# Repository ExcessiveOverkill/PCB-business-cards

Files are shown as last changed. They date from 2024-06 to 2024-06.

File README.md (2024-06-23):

# Persistence of vision display business cards

PCB cards designed for opensauce 2024 to give out to people

## Who is this repo for?
Anyone looking to make these cards for themselves or their own business.
It is NOT for people looking to make and sell the cards to others. (non-commercial use only)

## Software
- STM32CubeIDE
- python (numpy, cv2)
- Visual Studio Code

## Assembly
### The boards themselves
I ordered my PCBs from PCB way with .8mm thickness and ENIG coating since it is important to have a good contact surface for the batteries (and it looks nicer than HASL)

### Components
> [!WARNING]
> These exact parts I ordered in bulk from LCSC.
> The parts below are the closest matches I could find from DigiKey, but have not been tested yet

A DigiKey cart containing all of the needed components can be found [here](https://www.digikey.com/en/mylists/list/D8ND2J1IRM)
> [!IMPORTANT]
> The battery clips I used were from LCSC not DigiKey. The ones in the digikey cart have a slightly different footprint and may not fit perfectly.
> The exact clips I used can be found [here](https://www.lcsc.com/product-detail/Button-And-Strip-Battery-Connector_MYOUNG-MY-2032-30_C7525432.html)

Two standard CR2032 batteries are required, I used the cheap amazon ones.

### Placement
An interactive BOM can be found [here](opensauce2024/bom/ibom.html) (open in browser)

### Soldering
These boards are NOT designed to be hand-solderable.

I highly recommend at least a hotplate.

A stencil could be purchaced from a PCB manufacturer to make placing the solder paste easier, but it is not requred. (PCB and stencil files are in the repo)

The accelerometer is very susceptible to bad solder joints and will result in the card not activating when shaken. I had to resolder many of them to fix this.

## Programming
### Generating the graphics
Run "imageConverter.py", select which images or animations you want to display normally.

A second file select window will open for SECRET images to display. They will be displayed randomly according to the parameters set at the top of the python file.

Simply don't select anything if you do not want a secret image.

Images should be 32 pixel high PNGs, width does not matter, the card will show the entire image.

Once the images are selected, the program will show a demo of what will be displayed then write to a file defining the frame data.

### Programming the card
After the graphics have been saved, you simply build and upload the STM32 project using STM32CubeIDE.

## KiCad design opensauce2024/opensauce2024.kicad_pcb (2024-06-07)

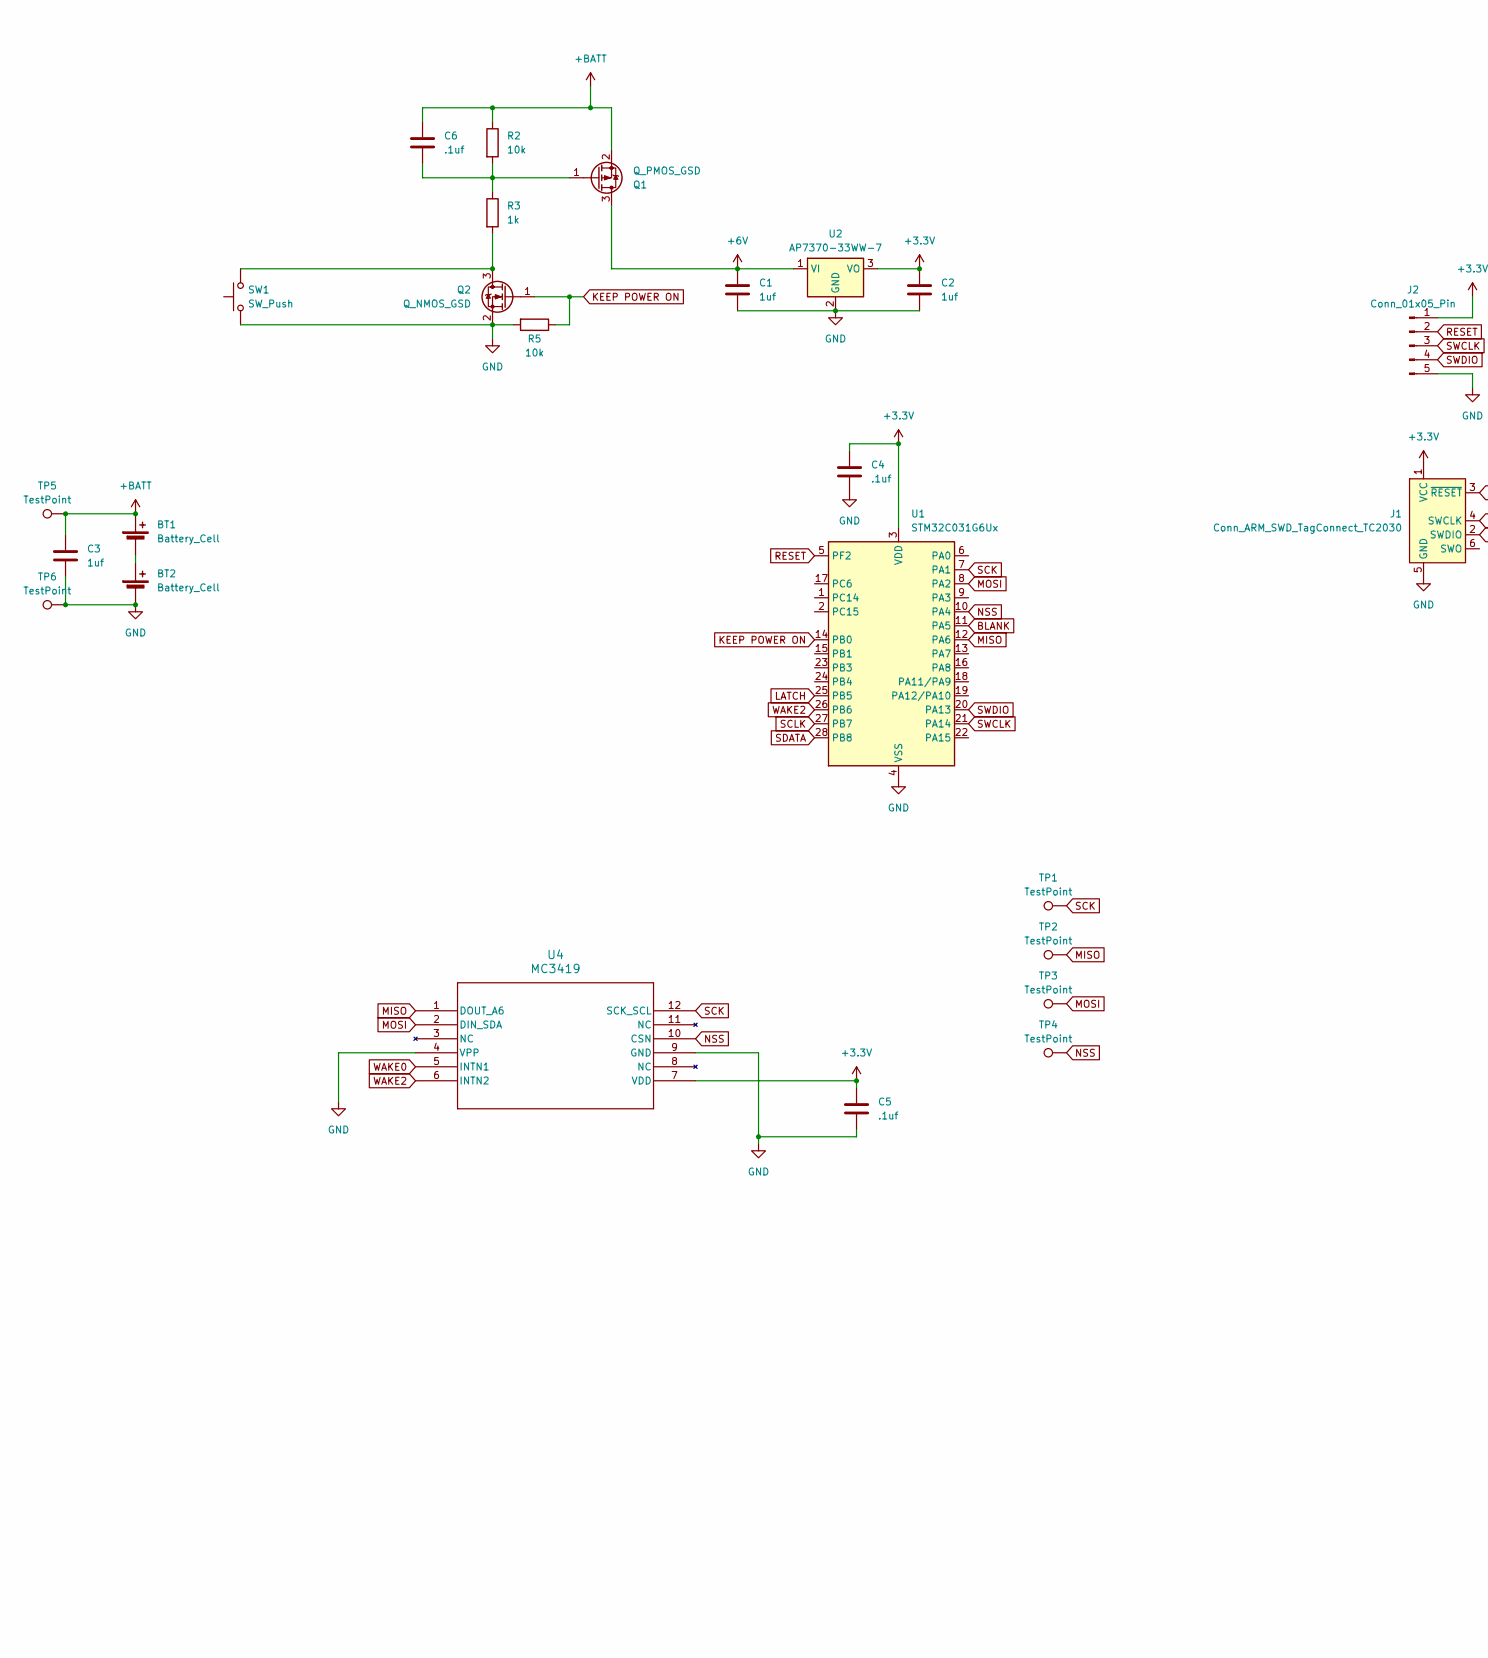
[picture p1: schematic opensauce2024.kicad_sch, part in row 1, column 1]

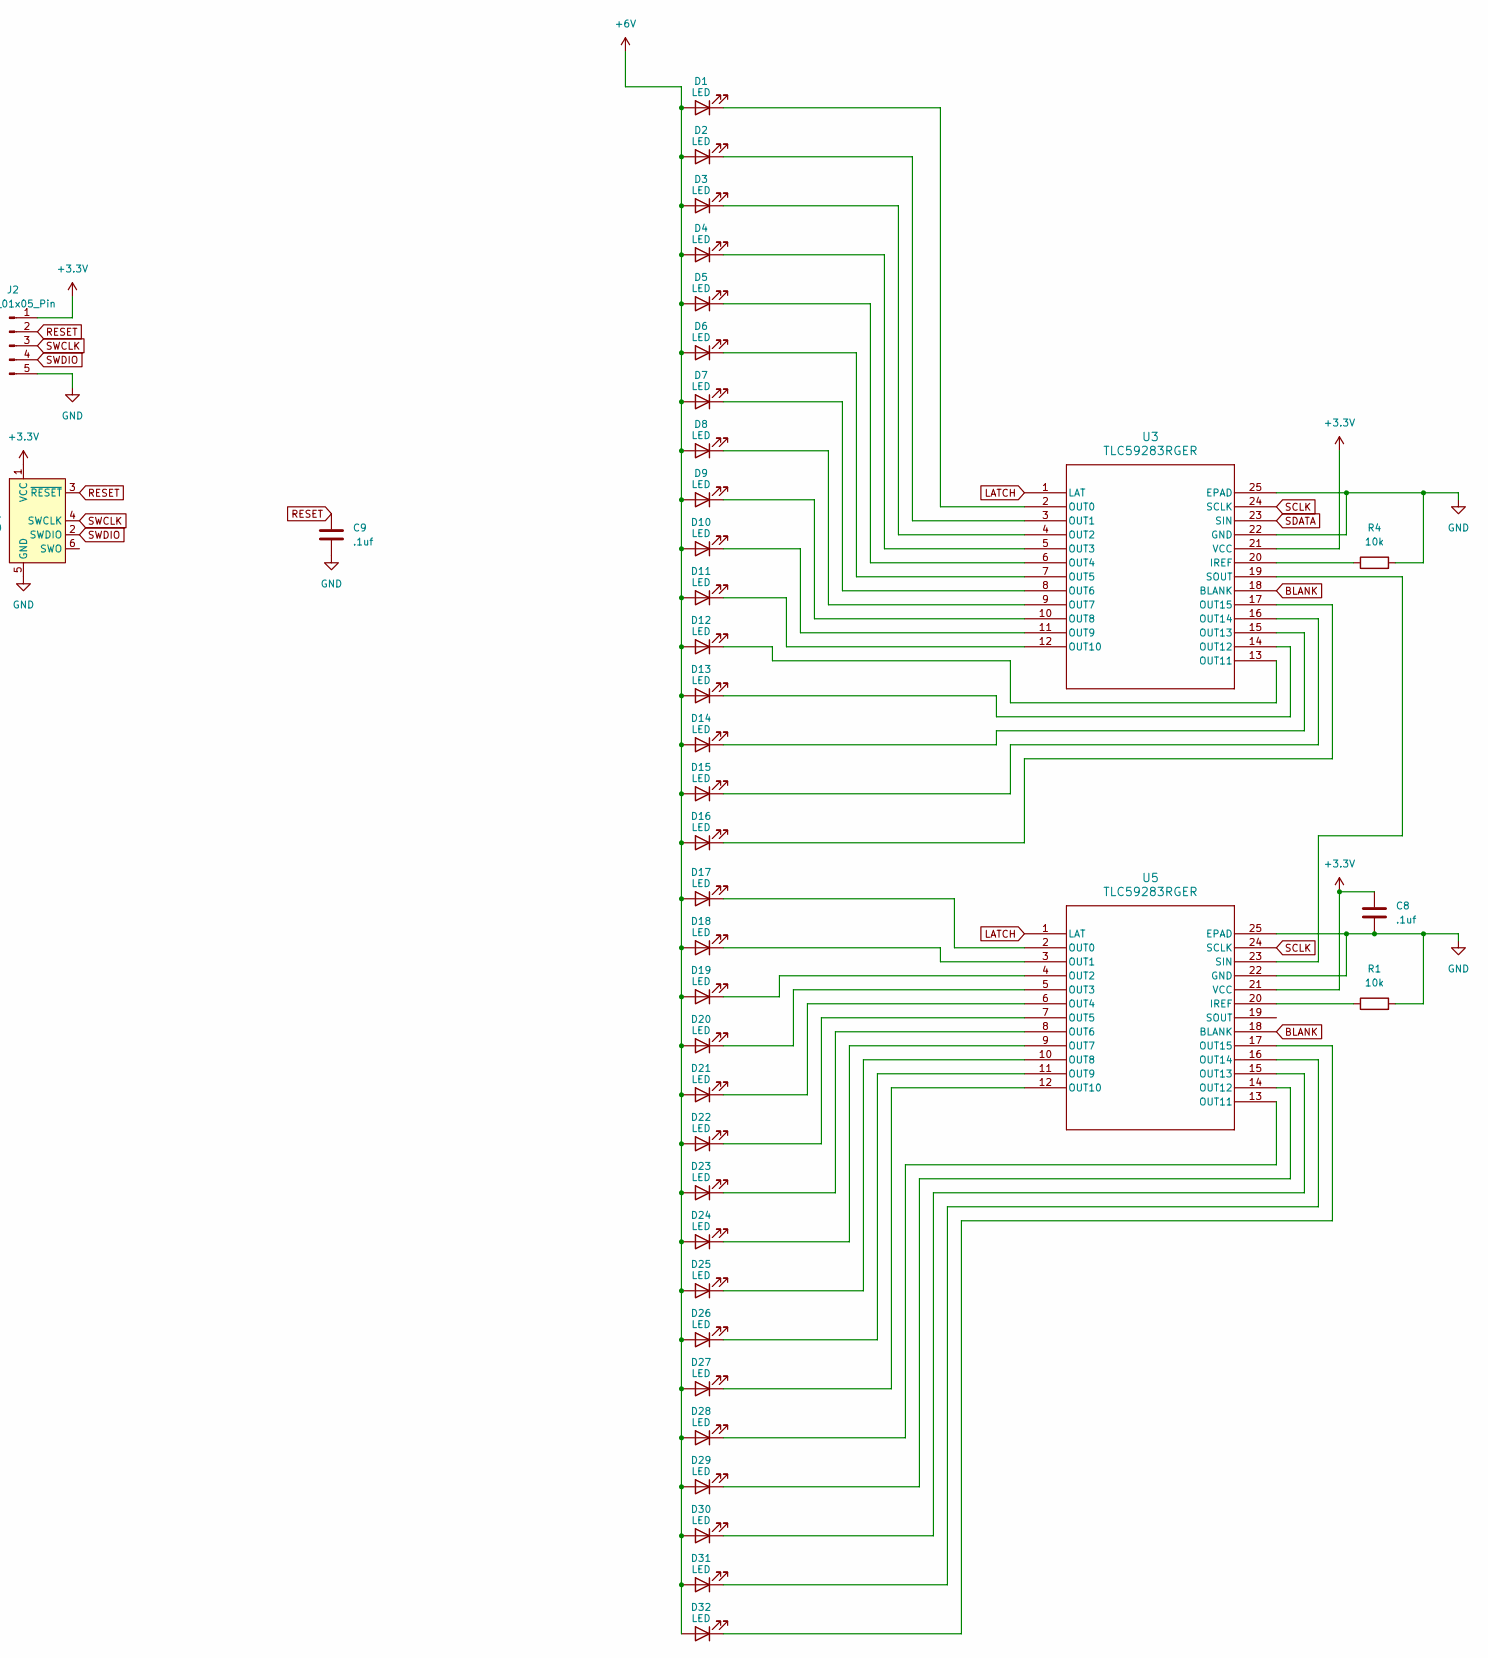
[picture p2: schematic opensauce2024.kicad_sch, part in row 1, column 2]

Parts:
BT1, BT2: Battery_Cell; cr2032
C1, C2, C3: 1uf; C_0603_1608Metric
C4, C5, C6, C8, C9: .1uf; C_0603_1608Metric
D1, D2, D3, D4, D5, D6, D7, D8, D9, D10, D11, D12, D13, D14, D15, D16, D17, D18, D19, D20, D21, D22, D23, D24, D25, D26, D27, D28, D29, D30, D31, D32: LED; LED_0603_1608Metric
J1: Conn_ARM_SWD_TagConnect_TC2030; Tag-Connect_TC2030-IDC-FP_2x03_P1.27mm_Vertical
J2: Conn_01x05_Pin; PinHeader_1x05_P2.54mm_Vertical
Q1: Q_PMOS_GSD; SOT-23
Q2: Q_NMOS_GSD; SOT-23
R1, R2, R4, R5: 10k; R_0603_1608Metric
R3: 1k; R_0603_1608Metric
SW1: SW_Push; SW_Push_1P1T_XKB_TS-1187A
TP1, TP2, TP3, TP4: TestPoint; TestPoint_Pad_D1.0mm
TP5, TP6: TestPoint; TestPoint_Pad_D2.0mm
U1: STM32C031G6Ux; QFN-28_4x4mm_P0.5mm
U2: AP7370-33WW-7; SOT25
U3, U5: TLC59283RGER; RGE24_2P1X2P1_TEX
U4: MC3419; LGA-12_2x2mm_P0.5mm

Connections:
+3.3V: C2.1, C4.1, C5.1, C8.1, J1.1 (VCC), J2.1, U1.3 (VDD), U2.3 (VO), U3.21 (VCC), U4.7 (VDD), U5.21 (VCC)
+6V: C1.1, D1.2 (A), D2.2 (A), D3.2 (A), D4.2 (A), D5.2 (A), D6.2 (A), D7.2 (A), D8.2 (A), D9.2 (A), D10.2 (A), D11.2 (A), D12.2 (A), D13.2 (A), D14.2 (A), D15.2 (A), D16.2 (A), D17.2 (A), D18.2 (A), D19.2 (A), D20.2 (A), D21.2 (A), D22.2 (A), D23.2 (A), D24.2 (A), D25.2 (A), D26.2 (A), D27.2 (A), D28.2 (A), D29.2 (A), D30.2 (A), D31.2 (A), D32.2 (A), Q1.3 (D), U2.1 (VI)
+BATT: BT1.1 (+), C3.1, C6.1, Q1.2 (S), R2.1, TP5.1
BLANK: U1.11 (PA5), U3.18 (BLANK), U5.18 (BLANK)
GND: BT2.2 (-), C1.2, C2.2, C3.2, C4.2, C5.2, C8.2, C9.2, J1.5 (GND), J2.5, Q2.2 (S), R1.2, R4.2, R5.2, SW1.1, TP6.1, U1.4 (VSS), U2.2 (GND), U3.22 (GND), U3.25 (EPAD), U4.4 (VPP), U4.9 (GND), U5.22 (GND), U5.25 (EPAD)
KEEP POWER ON: Q2.1 (G), R5.1, U1.14 (PB0)
LATCH: U1.25 (PB5), U3.1 (LAT), U5.1 (LAT)
MISO: TP2.1, U1.12 (PA6), U4.1 (DOUT_A6)
MOSI: TP3.1, U1.8 (PA2), U4.2 (DIN_SDA)
NSS: TP4.1, U1.10 (PA4), U4.10 (CSN)
unnamed: BT1.2 (-), BT2.1 (+)
unnamed: D1.1 (K), U3.2 (OUT0)
unnamed: D2.1 (K), U3.3 (OUT1)
unnamed: D3.1 (K), U3.4 (OUT2)
unnamed: D4.1 (K), U3.5 (OUT3)
unnamed: D5.1 (K), U3.6 (OUT4)
unnamed: D6.1 (K), U3.7 (OUT5)
unnamed: D7.1 (K), U3.8 (OUT6)
unnamed: D8.1 (K), U3.9 (OUT7)
unnamed: D9.1 (K), U3.10 (OUT8)
unnamed: D10.1 (K), U3.11 (OUT9)
unnamed: D11.1 (K), U3.12 (OUT10)
unnamed: D12.1 (K), U3.13 (OUT11)
unnamed: D13.1 (K), U3.14 (OUT12)
unnamed: D14.1 (K), U3.15 (OUT13)
unnamed: D15.1 (K), U3.16 (OUT14)
unnamed: D16.1 (K), U3.17 (OUT15)
unnamed: D17.1 (K), U5.2 (OUT0)
unnamed: D18.1 (K), U5.3 (OUT1)
unnamed: D19.1 (K), U5.4 (OUT2)
unnamed: D20.1 (K), U5.5 (OUT3)
unnamed: D21.1 (K), U5.6 (OUT4)
unnamed: D22.1 (K), U5.7 (OUT5)
unnamed: D23.1 (K), U5.8 (OUT6)
unnamed: D24.1 (K), U5.9 (OUT7)
unnamed: D25.1 (K), U5.10 (OUT8)
unnamed: D26.1 (K), U5.11 (OUT9)
unnamed: D27.1 (K), U5.12 (OUT10)
unnamed: D28.1 (K), U5.13 (OUT11)
unnamed: D29.1 (K), U5.14 (OUT12)
unnamed: D30.1 (K), U5.15 (OUT13)
unnamed: D31.1 (K), U5.16 (OUT14)
unnamed: D32.1 (K), U5.17 (OUT15)
unnamed: C6.2, Q1.1 (G), R2.2, R3.1
unnamed: Q2.3 (D), R3.2, SW1.2
unnamed: R4.1, U3.20 (IREF)
unnamed: U3.19 (SOUT), U5.23 (SIN)
unnamed: R1.1, U5.20 (IREF)
RESET: C9.1, J1.3 (~RESET), J2.2, U1.5 (PF2)
SCK: TP1.1, U1.7 (PA1), U4.12 (SCK_SCL)
SCLK: U1.27 (PB7), U3.24 (SCLK), U5.24 (SCLK)
SDATA: U1.28 (PB8), U3.23 (SIN)
SWCLK: J1.4 (SWCLK), J2.3, U1.21 (PA14)
SWDIO: J1.2 (SWDIO), J2.4, U1.20 (PA13)
WAKE0: U4.5 (INTN1)
WAKE2: U1.26 (PB6), U4.6 (INTN2)

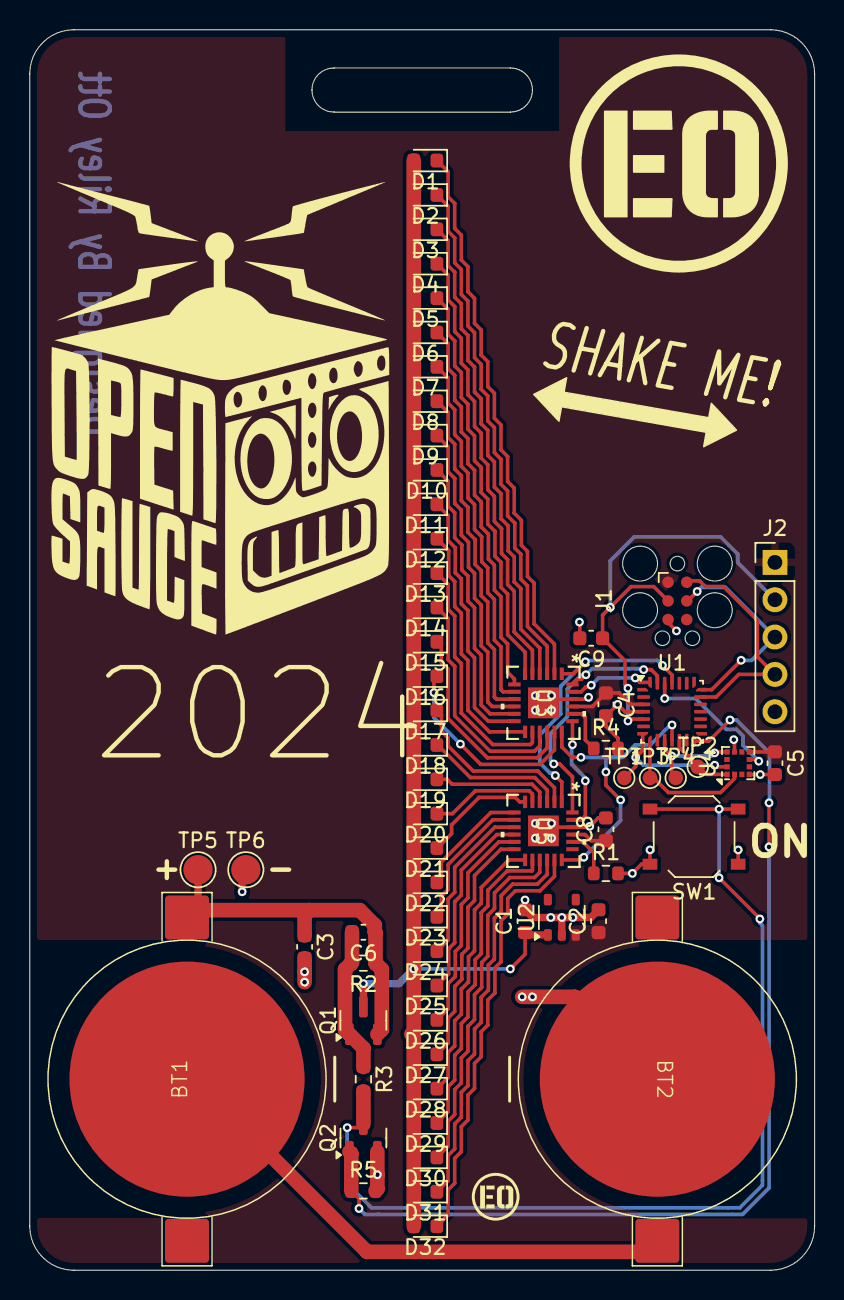
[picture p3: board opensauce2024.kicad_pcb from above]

Board: 2 copper layers, 53.4 x 84.4 mm, 63 parts (0 on the bottom side), 55 nets.

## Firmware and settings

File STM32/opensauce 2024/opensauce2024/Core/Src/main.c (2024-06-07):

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
/* Includes ------------------------------------------------------------------*/
#include "main.h"

/* USER CODE BEGIN Includes */
#include "ledDrivers.h"
#include "imageData.h"
#include "math.h"
/* USER CODE END Includes */

/* USER CODE BEGIN PD */
#define POWER_OFF_DELAY 30	// how many seconds of no movement before powering down
#define LED_ENABLE_ACCELERATION 6000

// use measured x accel values as "random" input
// max is 0x7FFE
// min is 1
// a point is counted each time the actual measured value falls between high and low range (inclusive), once enough points are accumulated, the random event is triggered
#define RANDOM_HIGH_RANGE 0x3FFF + RANDOM_CHANCE  	// mid-scale
#define RANDOM_LOW_RANGE 0x3FFF - RANDOM_CHANCE		// the wider this range, the more likely it will match
#define RANDOM_POINTS_REQUIRED RANDOM_POINTS
#define SECRET_IMAGE_DISPLAY_CYCLES SECRET_DISPLAY_CYCLES	// number of cycles to display the secret image once the random threshold is reached

//#define ANGLE_STABILIZATION_MODE 1	// enable stabilization mode, this displays animation frames based on the tilt angle of the card instead of playing the animation. frame display cycles should be set to 1 when using this

#define PI 3.14159265359


/* USER CODE END PD */


SPI_HandleTypeDef hspi1;

TIM_HandleTypeDef htim1;

/* USER CODE BEGIN PV */

// write addresses
const uint8_t ACCEL_MODE = 0x07;
const uint8_t ACCEL_SAMPLE_RATE = 0x08;
const uint8_t ACCEL_RANGE = 0x20;
const uint8_t ACCEL_INTERRUPT_ENABLE = 0x06;
const uint8_t ACCEL_GPIO_CONTROL = 0x33;
const uint8_t ACCEL_COMMUNICATION_CONTROL = 0x31;
const uint8_t ACCEL_INTERRUPT_STATUS = 0x14;

// read addresses
const uint8_t ACCEL_STATUS = 0x05 + 128;
const uint8_t ACCEL_READ_COUNT = 0x4b + 128;
const uint8_t ACCEL_X_DATA = 0x0d + 128;
const uint8_t ACCEL_RUN_STATUS = 0x13 + 128;

/* USER CODE END PV */

void SystemClock_Config(void);
static void MX_GPIO_Init(void);
static void MX_SPI1_Init(void);
static void MX_TIM1_Init(void);
/**
  * @brief  The application entry point.
  * @retval int
  */
int main(void)
{

  /* USER CODE BEGIN 1 */
	FLASH_OBProgramInitTypeDef OB;

	HAL_FLASHEx_OBGetConfig(&OB);
	if((OB.USERConfig & OB_BOR_ENABLE)){
	   HAL_FLASH_Unlock();
	   HAL_FLASH_OB_Unlock();

	   OB.OptionType = OPTIONBYTE_USER;
	   OB.USERType = OB_USER_BOR_EN;
	   OB.USERConfig = OB_BOR_DISABLE;

	   if ( HAL_FLASHEx_OBProgram(&OB) != HAL_OK )
		  {
			  HAL_FLASH_OB_Lock();
			  HAL_FLASH_Lock();
			  return HAL_ERROR;
		  }

		  HAL_FLASH_OB_Launch();

		  /* We should not make it past the Launch, so lock
		   * flash memory and return an error from function
		   */
		  HAL_FLASH_OB_Lock();
		  HAL_FLASH_Lock();
		  return HAL_ERROR;
	}

  /* USER CODE END 1 */

  /* MCU Configuration--------------------------------------------------------*/

  /* Reset of all peripherals, Initializes the Flash interface and the Systick. */
  HAL_Init();

  /* Configure the system clock */
  SystemClock_Config();

  /* Initialize all configured peripherals */
  MX_GPIO_Init();
  MX_SPI1_Init();
  MX_TIM1_Init();
  /* USER CODE BEGIN 2 */

  TIM1->CR1 |= 1;

  // lock on power
  HAL_GPIO_WritePin(KEEP_POWER_ON_GPIO_Port, KEEP_POWER_ON_Pin, GPIO_PIN_SET);
  //HAL_Delay(100);
  disableLEDs();
  setLEDs(0x80000001);
  enableLEDs();
  HAL_Delay(100);
  setLEDs(0);

  uint32_t tick_count = 0;
  uint32_t last_active_tick_count = 0;

  const uint32_t imageData[IMAGE_LENGTH] = IMAGE_DATA;
  const uint8_t normal_frame_cycles[IMAGE_LENGTH/FRAME_LENGTH] = FRAME_DISPLAY_CYCLES;

  #ifdef SECRET_IMAGE_DATA
  	  const uint32_t secretImageData[SECRET_IMAGE_LENGTH] = SECRET_IMAGE_DATA;
  	  const uint8_t secret_frame_cycles[SECRET_IMAGE_LENGTH/SECRET_FRAME_LENGTH] = SECRET_FRAME_DISPLAY_CYCLES;
  #endif


  char spi_buf[10];
  char spi_read_buf[10];

  #ifdef ANGLE_STABILIZATION_MODE
  	  int16_t y_accel_raw = 0;
  	  int32_t angle_step = 0;
  	  int32_t x_accel_zero_average = 0;
  	  int32_t y_accel_zero_average = 0;
  #endif

  int16_t x_accel_raw = 0;


  int32_t low_cut_integrator_rate = 10; // max accel magnitude to reduce toward zero each cycle. this is used to remove affects of gravity
  int32_t x_low_cut_integrator = 0;

  int32_t x_accel = 0;
  int32_t x_accel_interpolated = 0;
  int32_t x_accel_previous = 0;
  uint32_t accel_last_update_time = 0;	// us
  uint32_t accel_update_period = 1000; 	// us (1000Hz)
  int32_t max_dynamic_accel = 0x7FFF; // acceleration needed to reach ends of image, this should adjust based on the measured max acceleration


  int32_t x_accel_magnitude_average = 0;

  int32_t image_line = 0;

  int32_t max_cycle_accel = 0;
  int32_t min_cycle_accel = 0;
  uint32_t max_cycle_accel_time = 0;
  uint32_t min_cycle_accel_time = 0;

  uint32_t estimated_next_edge_time = 0;	// when we think we will be at the end of the shake motion again
  uint32_t frame_trigger_time = 0xFFFFFFFF;

  uint32_t random_points = 0;
  int32_t image_length = IMAGE_LENGTH;
  int32_t frame_length = FRAME_LENGTH;
  
  uint32_t current_frame_cycle = 0;
  uint32_t frame_display_cycles = normal_frame_cycles[0];

  uint32_t current_frame = 0;

  uint32_t secret_display_cycles = 0;

  uint32_t accel_read_attemps = 0;

  // send nothing to get SPI clk level set correctly
  HAL_SPI_Transmit(&hspi1, (uint8_t *)spi_buf, 1, 1);

  // configure accelerometer

  ACCEL_SELECT_GPIO_Port->ODR &= ~(1 << 4);
  spi_buf[0] = ACCEL_MODE;
  spi_buf[1] = 0b00000000;	// set to standby mode
  HAL_SPI_Transmit(&hspi1, (uint8_t *)spi_buf, 2, 1);
  ACCEL_SELECT_GPIO_Port->ODR |= (1 << 4);

  HAL_Delay(1);

  ACCEL_SELECT_GPIO_Port->ODR &= ~(1 << 4);
  spi_buf[0] = ACCEL_SAMPLE_RATE;
  spi_buf[1] = 0x0E;	// set sample rate (1000 Hz)
  HAL_SPI_Transmit(&hspi1, (uint8_t *)spi_buf, 2, 1);
  ACCEL_SELECT_GPIO_Port->ODR |= (1 << 4);

  ACCEL_SELECT_GPIO_Port->ODR &= ~(1 << 4);
  spi_buf[0] = ACCEL_INTERRUPT_ENABLE;
  spi_buf[1] = 0x80;	// enable sample (ACQ) interrupt
  HAL_SPI_Transmit(&hspi1, (uint8_t *)spi_buf, 2, 1);
  ACCEL_SELECT_GPIO_Port->ODR |= (1 << 4);

  ACCEL_SELECT_GPIO_Port->ODR &= ~(1 << 4);
  spi_buf[0] = ACCEL_GPIO_CONTROL;
  spi_buf[1] = 0xC0;	// set INTN2 pin as push/pull active high
  HAL_SPI_Transmit(&hspi1, (uint8_t *)spi_buf, 2, 1);
  ACCEL_SELECT_GPIO_Port->ODR |= (1 << 4);

  ACCEL_SELECT_GPIO_Port->ODR &= ~(1 << 4);
  spi_buf[0] = ACCEL_COMMUNICATION_CONTROL;
  spi_buf[1] = 0x10;	// swap INTN output pins
  HAL_SPI_Transmit(&hspi1, (uint8_t *)spi_buf, 2, 1);
  ACCEL_SELECT_GPIO_Port->ODR |= (1 << 4);

  ACCEL_SELECT_GPIO_Port->ODR &= ~(1 << 4);
  spi_buf[0] = ACCEL_RANGE;
  spi_buf[1] = 0b00100000;	// set +- 8G's
  HAL_SPI_Transmit(&hspi1, (uint8_t *)spi_buf, 2, 1);
  ACCEL_SELECT_GPIO_Port->ODR |= (1 << 4);

  ACCEL_SELECT_GPIO_Port->ODR &= ~(1 << 4);
  spi_buf[0] = ACCEL_MODE;
  spi_buf[1] = 0b00000001;	// set to wake mode
  HAL_SPI_Transmit(&hspi1, (uint8_t *)spi_buf, 2, 1);
  ACCEL_SELECT_GPIO_Port->ODR |= (1 << 4);


  tick_count = (tick_count & 0xFFFF0000) + TIM1->CNT;
  	if(TIM1->SR & 0b1){
  		tick_count += 0x10000;
  		TIM1->SR &= ~(1);
  	}

  accel_last_update_time = tick_count;


  /* USER CODE END 2 */

  /* Infinite loop */
  /* USER CODE BEGIN WHILE */
  while (1)
  {
	tick_count = (tick_count & 0xFFFF0000) + TIM1->CNT;
	if(TIM1->SR & 0b1){
		tick_count += 0x10000;
		TIM1->SR &= ~(1);
	}

	accel_read_attemps = 5;
	while(ACCEL_INTERRUPT_GPIO_Port->IDR & (1 << 6) && accel_read_attemps > 0){

		tick_count = (tick_count & 0xFFFF0000) + TIM1->CNT;
		if(TIM1->SR & 0b1){
			tick_count += 0x10000;
			TIM1->SR &= ~(1);
		}

		accel_read_attemps--;
		// read XYZ accel values
		ACCEL_SELECT_GPIO_Port->ODR &= ~(1 << 4);
		spi_buf[0] = (uint8_t)ACCEL_X_DATA;
		spi_buf[1] = 0;
		spi_buf[2] = 0;
		spi_buf[4] = 0;
		HAL_SPI_TransmitReceive(&hspi1, (uint8_t *)spi_buf, (uint8_t *)spi_read_buf, 8, 1);
		ACCEL_SELECT_GPIO_Port->ODR |= (1 << 4);

		// clear interrupt
		ACCEL_SELECT_GPIO_Port->ODR &= ~(1 << 4);
		spi_buf[0] = ACCEL_INTERRUPT_STATUS;
		spi_buf[1] = 0;
		HAL_SPI_Transmit(&hspi1, (uint8_t *)spi_buf, 2, 1);
		ACCEL_SELECT_GPIO_Port->ODR |= (1 << 4);

		accel_update_period = tick_count - accel_last_update_time;
		accel_last_update_time = tick_count;

		x_accel_raw = spi_read_buf[2] | spi_read_buf[3] << 8;
        #ifdef ANGLE_STABILIZATION_MODE
			y_accel_raw = spi_read_buf[4] | spi_read_buf[5] << 8;
		#endif
		//z_accel_raw = spi_read_buf[6] | spi_read_buf[7] << 8;


		if(x_accel_magnitude_average > LED_ENABLE_ACCELERATION){
			if(x_accel_previous < 0 && x_accel >= 0){	// transitioned from negative to positive acceleration
				max_cycle_accel = 0;	// clear previous max recorded accel
				estimated_next_edge_time = (min_cycle_accel_time-max_cycle_accel_time) + min_cycle_accel_time;

				#ifdef ANGLE_STABILIZATION_MODE
					// save angle when there should be negligible affect from shaking
					x_accel_zero_average -= (x_accel_zero_average - x_accel_raw) / 5;
					y_accel_zero_average -= (y_accel_zero_average - y_accel_raw) / 5;
					angle_step = atan2(x_accel_zero_average, y_accel_zero_average) * ((IMAGE_LENGTH/FRAME_LENGTH) / (2*PI)) + ((IMAGE_LENGTH/FRAME_LENGTH) / 2);
				#endif
			}

			if(x_accel_previous > 0 && x_accel <= 0){	// transitioned from positive to negative acceleration
				min_cycle_accel = 0;	// clear previous min recorded accel
				estimated_next_edge_time = (max_cycle_accel_time-min_cycle_accel_time) + max_cycle_accel_time;

				#ifdef ANGLE_STABILIZATION_MODE
					// save angle when there should be negligible affect from shaking
					x_accel_zero_average -= (x_accel_zero_average - x_accel_raw) / 5;
					y_accel_zero_average -= (y_accel_zero_average - y_accel_raw) / 5;
					angle_step = atan2(x_accel_zero_average, y_accel_zero_average) * ((IMAGE_LENGTH/FRAME_LENGTH) / (2*PI)) + ((IMAGE_LENGTH/FRAME_LENGTH) / 2);
				#endif
			}
		}

		if(estimated_next_edge_time > tick_count + 500000) estimated_next_edge_time = tick_count;

		x_accel_previous = x_accel;


		// integrate towards zero to cancel constant acceleration (gravity)
		x_accel = x_accel_raw + x_low_cut_integrator;

		// random event generation
		if((x_accel >= RANDOM_LOW_RANGE && x_accel <= RANDOM_HIGH_RANGE) && secret_display_cycles==0) random_points++;


		// run integrator
		if(x_accel > low_cut_integrator_rate){
			x_low_cut_integrator -= low_cut_integrator_rate;
		}
		else if(x_accel < -low_cut_integrator_rate){
			x_low_cut_integrator += low_cut_integrator_rate;
		}
		else{
			x_low_cut_integrator -= x_accel;
		}

		// estimate average magnitude (used to detect motion)
		x_accel_magnitude_average += (abs(x_accel) - x_accel_magnitude_average) / 200;


		if(x_accel>max_cycle_accel){
			max_cycle_accel = x_accel;
			max_cycle_accel_time = tick_count;
		}

		if(x_accel<min_cycle_accel){
			min_cycle_accel = x_accel;
			min_cycle_accel_time = tick_count;
		}

	}



	// interpolate acceleration steps to get a smooth change
	x_accel_interpolated = x_accel_previous * (int32_t)accel_update_period + (x_accel / (int32_t)(tick_count-accel_last_update_time));
	x_accel_interpolated /= (int32_t)accel_update_period;
	
	
	// increment display frame cycle counter
	if(tick_count >= frame_trigger_time && current_frame_cycle == 0){	// reset counter and increment to next frame index

		current_frame++;
		frame_display_cycles = normal_frame_cycles[current_frame];
		current_frame_cycle = frame_display_cycles;

		if(current_frame * frame_length > image_length-frame_length){
			current_frame = 0;		// loop back to first frame once end of image is reached
			frame_display_cycles = normal_frame_cycles[current_frame];
			current_frame_cycle = frame_display_cycles;

			if(secret_display_cycles != 0){
				secret_display_cycles--;	// decrement secret display cycles since we went through all of the frames

				if(secret_display_cycles == 0){		// switch back to normal image when secret cycles are up
					image_length = IMAGE_LENGTH;
					frame_length = FRAME_LENGTH;
					current_frame = 0;	// pick up where we left off
					frame_display_cycles = normal_frame_cycles[current_frame];
					current_frame_cycle = frame_display_cycles;
				}
			}
		}
		
		#ifdef SECRET_IMAGE_DATA
			if(random_points >= RANDOM_POINTS_REQUIRED && current_frame == 0){	// switch to secret image, random points are not generated while secret_display_cycles != 0
				random_points = 0;
				image_length = SECRET_IMAGE_LENGTH;
				frame_length = SECRET_FRAME_LENGTH;
				secret_display_cycles = SECRET_IMAGE_DISPLAY_CYCLES;
				current_frame = 0;	// reset frame counter so we start at first frame of animation
				frame_display_cycles = secret_frame_cycles[current_frame];
				current_frame_cycle = frame_display_cycles;
			}
		#endif

		#ifdef ANGLE_STABILIZATION_MODE
			// select frame based on tilt angle
			if(secret_display_cycles != 0){
				secret_display_cycles--;	// decrement secret display cycles

				if(secret_display_cycles == 0){		// switch back to normal image when secret cycles are up
					image_length = IMAGE_LENGTH;
					frame_length = FRAME_LENGTH;
					frame_display_cycles = FRAME_DISPLAY_CYCLES;
				}
			}

			current_frame = angle_step + (IMAGE_LENGTH/FRAME_LENGTH) - 1;
			current_frame %= (IMAGE_LENGTH/FRAME_LENGTH);
		#endif
  	    
	}

    if(tick_count >= frame_trigger_time && current_frame_cycle != 0 && frame_trigger_time < estimated_next_edge_time){	// decrement counter
    	frame_trigger_time = estimated_next_edge_time;
    	current_frame_cycle--;
    }

    if(current_frame_cycle==0) frame_trigger_time = estimated_next_edge_time;



  	// find line of image to display based on current acceleration and image length
	image_line =  ((x_accel_interpolated + max_dynamic_accel/2) / (max_dynamic_accel / frame_length)) + current_frame * frame_length;

	// display image if image_line is valid and motion is detected
	if(image_line >= current_frame * frame_length && image_line < (current_frame+1) * frame_length && x_accel_magnitude_average > LED_ENABLE_ACCELERATION){
		#ifdef SECRET_IMAGE_DATA
			if(secret_display_cycles > 0){
				setLEDs(secretImageData[image_line]);
		  	}
		  	else{
		  		setLEDs(imageData[image_line]);
		  	}
		#else
			setLEDs(imageData[image_line]);
		#endif

		last_active_tick_count = tick_count;
	}
	else{
		setLEDs(0);
	}

	if(x_accel_magnitude_average < LED_ENABLE_ACCELERATION){
		// reset animation variables when card is no longer being shaken
		image_length = IMAGE_LENGTH;
		frame_length = FRAME_LENGTH;
		frame_display_cycles = normal_frame_cycles[0];
		current_frame = 0;	// reset frame counter so we start at first frame of animation
	}


	if(tick_count - last_active_tick_count >= 1000000 * POWER_OFF_DELAY){
		// shut down
		setLEDs(0xFFFFFFFF);
		HAL_GPIO_WritePin(KEEP_POWER_ON_GPIO_Port, KEEP_POWER_ON_Pin, GPIO_PIN_RESET);
		NVIC_SystemReset();

	}

    /* USER CODE END WHILE */

    /* USER CODE BEGIN 3 */
  }
  /* USER CODE END 3 */
}

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


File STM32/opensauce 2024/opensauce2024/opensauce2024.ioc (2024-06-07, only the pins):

Mcu.UserName=STM32C031G6Ux
PA1.Signal=SPI1_SCK
PA13.Signal=DEBUG_SWDIO
PA14-BOOT0.Signal=DEBUG_SWCLK
PA2.Signal=SPI1_MOSI
PA4.GPIO_Label=ACCEL_SELECT
PA4.Signal=GPIO_Output
PA5.GPIO_Label=LED BLANK
PA5.Signal=GPIO_Output
PA6.Signal=SPI1_MISO
PB0.GPIO_Label=KEEP POWER ON
PB0.Signal=GPIO_Output
PB5.GPIO_Label=LED DATA LATCH
PB5.Signal=GPIO_Output
PB6.GPIO_Label=ACCEL_INTERRUPT
PB6.Signal=GPIO_Input
PB7.GPIO_Label=LED DATA CLOCK
PB7.Signal=GPIO_Output
PB8.GPIO_Label=LED DATA
PB8.Signal=GPIO_Output

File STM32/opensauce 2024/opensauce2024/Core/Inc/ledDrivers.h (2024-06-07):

/*
 * ledDrivers.h
 *
 *  Created on: May 13, 2024
 *      Author: voids
 */

#ifndef INC_LEDDRIVERS_H_
#define INC_LEDDRIVERS_H_

#include "stm32c0xx_hal.h"

#define LED_BLANK_Pin GPIO_PIN_5
#define LED_BLANK_GPIO_Port GPIOA
#define KEEP_POWER_ON_Pin GPIO_PIN_0
#define KEEP_POWER_ON_GPIO_Port GPIOB
#define LED_DATA_LATCH_Pin GPIO_PIN_5
#define LED_DATA_LATCH_GPIO_Port GPIOB
#define LED_DATA_CLOCK_Pin GPIO_PIN_7
#define LED_DATA_CLOCK_GPIO_Port GPIOB
#define LED_DATA_Pin GPIO_PIN_8
#define LED_DATA_GPIO_Port GPIOB

void disableLEDs();
void enableLEDs();
void setLEDs(uint32_t data);

#endif /* INC_LEDDRIVERS_H_ */

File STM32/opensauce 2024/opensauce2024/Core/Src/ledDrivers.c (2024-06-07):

#include "ledDrivers.h"


void disableLEDs(){
	// force all outputs off
	HAL_GPIO_WritePin(LED_BLANK_GPIO_Port, LED_BLANK_Pin, GPIO_PIN_SET);
}

void enableLEDs(){
	// enable outputs
	HAL_GPIO_WritePin(LED_BLANK_GPIO_Port, LED_BLANK_Pin, GPIO_PIN_RESET);
}

void setLEDs(uint32_t data){
	// write data to leds

	uint32_t tempData = data;

	for (int i=0; i < 32; i++){

		/*
		GPIO_PinState dataPinState = (tempData & 0b1) ? GPIO_PIN_SET : GPIO_PIN_RESET;

		// write to data pin
		HAL_GPIO_WritePin(LED_DATA_GPIO_Port, LED_DATA_Pin, dataPinState);

		// cycle clock to increment data
		HAL_GPIO_WritePin(LED_DATA_CLOCK_GPIO_Port, LED_DATA_CLOCK_Pin, GPIO_PIN_SET);
		// might need a delay here or slower GPIO clock
		HAL_GPIO_WritePin(LED_DATA_CLOCK_GPIO_Port, LED_DATA_CLOCK_Pin, GPIO_PIN_RESET);

		tempData = tempData >> 1;
		*/

		if(tempData & 0b1){
			LED_DATA_GPIO_Port->ODR |= (1 << 8);
		}
		else{
			LED_DATA_GPIO_Port->ODR &= ~(1 << 8);
		}

		LED_DATA_CLOCK_GPIO_Port->ODR |= (1 << 7);
		LED_DATA_CLOCK_GPIO_Port->ODR &= ~(1 << 7);

		tempData = tempData >> 1;
	}

	// cycle latch to update outputs
	HAL_GPIO_WritePin(LED_DATA_LATCH_GPIO_Port, LED_DATA_LATCH_Pin, GPIO_PIN_SET);
	// might need a delay here or slower GPIO clock
	HAL_GPIO_WritePin(LED_DATA_LATCH_GPIO_Port, LED_DATA_LATCH_Pin, GPIO_PIN_RESET);

}

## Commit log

2024-06-07 Add all files
    [opensauce2024-B_Cu.gbr, opensauce2024-B_Mask.gbr, opensauce2024-B_Paste.gbr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]
2024-06-23 Create PCB-business-cards.code-workspace

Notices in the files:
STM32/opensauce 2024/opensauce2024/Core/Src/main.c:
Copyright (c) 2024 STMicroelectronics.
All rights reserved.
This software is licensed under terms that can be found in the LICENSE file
